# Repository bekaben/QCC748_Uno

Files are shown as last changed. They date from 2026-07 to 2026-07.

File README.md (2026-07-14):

# Arduino Uno Compatible Board Based on Qualcomm QCC748 SOM

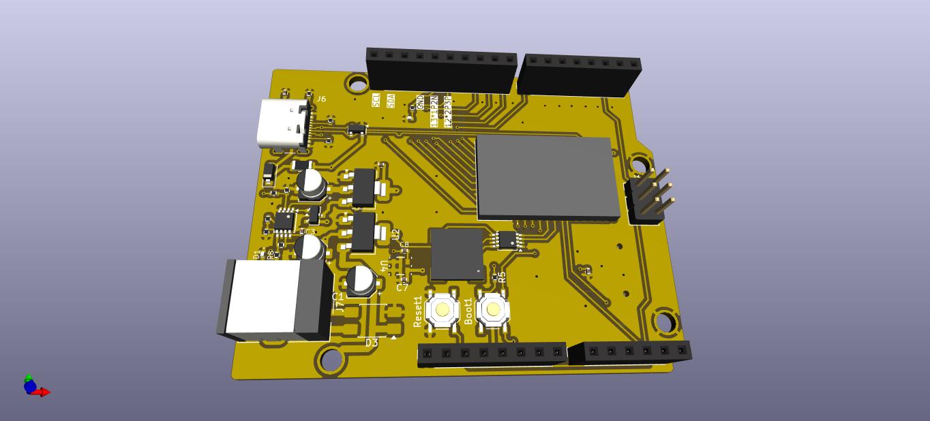
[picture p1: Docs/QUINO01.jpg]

<br>
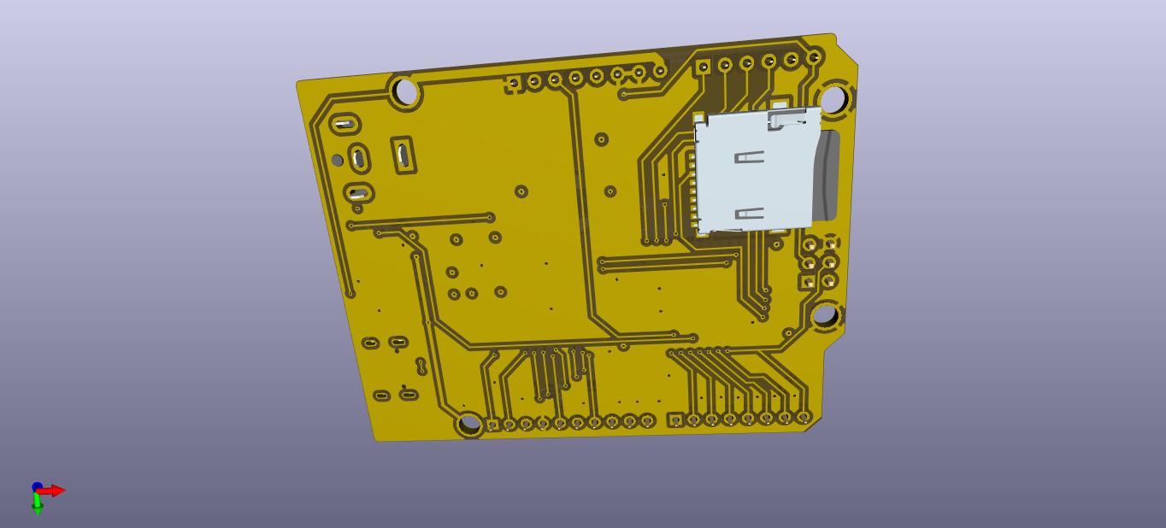
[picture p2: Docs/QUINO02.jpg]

<br>

This is a custom Arduino Uno-compatible board built around the Qualcomm QCC748 System-on-Module (SOM). This repository contains the full schematic, PCB layout, and supporting documentation for the board design.

## 🔧 Overview

This project implements an Arduino Uno form-factor development board using the Qualcomm QCC748 SOM as the core processing module. The design maintains compatibility with the Arduino Uno pinout while leveraging the QCC748's capabilities for enhanced wireless connectivity and processing performance. In addition, the board includes a speaker, microphone, and MicroSD card interface.

## Key Goals

\- ✅ Arduino Uno R3 mechanical footprint compatibility

\- ✅ Standard Arduino header pinout

\- ✅ USB programming interface

\- ✅ Power supply regulation (5V / 3.3V)

\- ✅ Wireless connectivity via QCC748 integrated Wifi and Bluetooth

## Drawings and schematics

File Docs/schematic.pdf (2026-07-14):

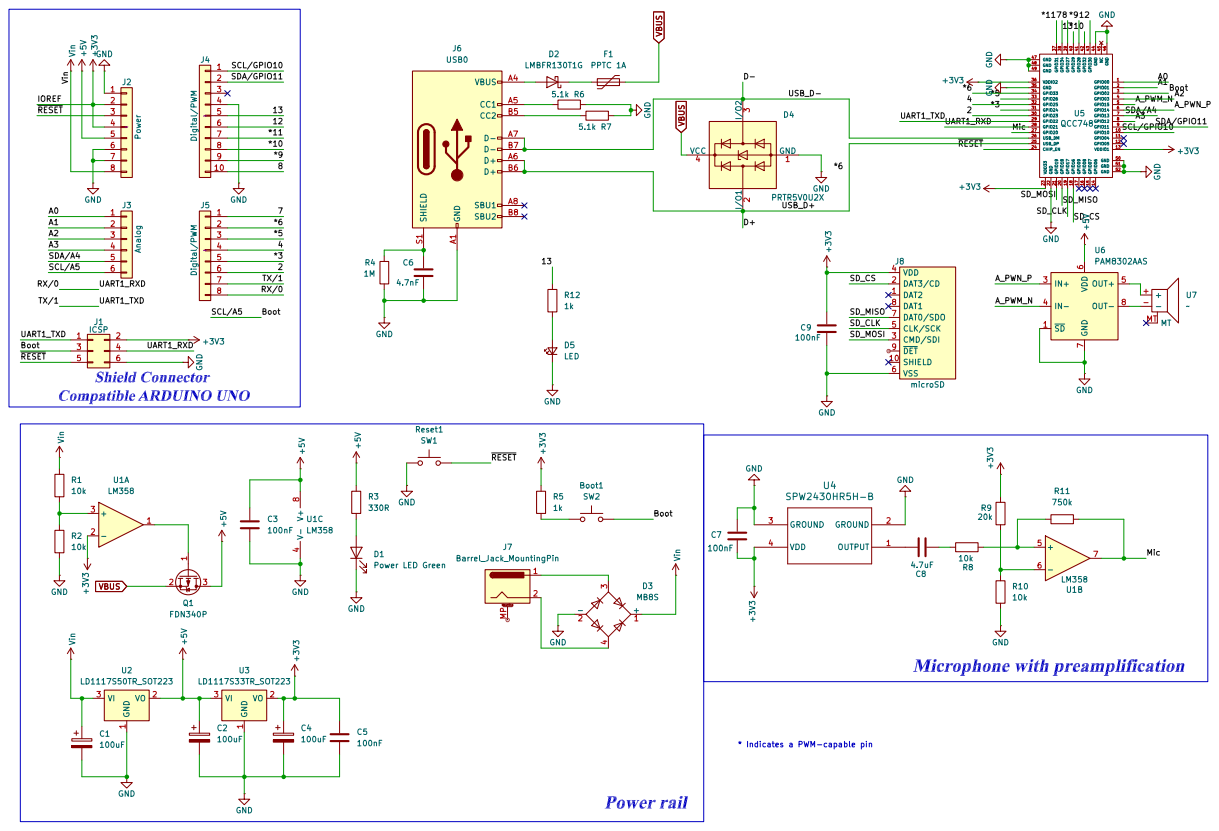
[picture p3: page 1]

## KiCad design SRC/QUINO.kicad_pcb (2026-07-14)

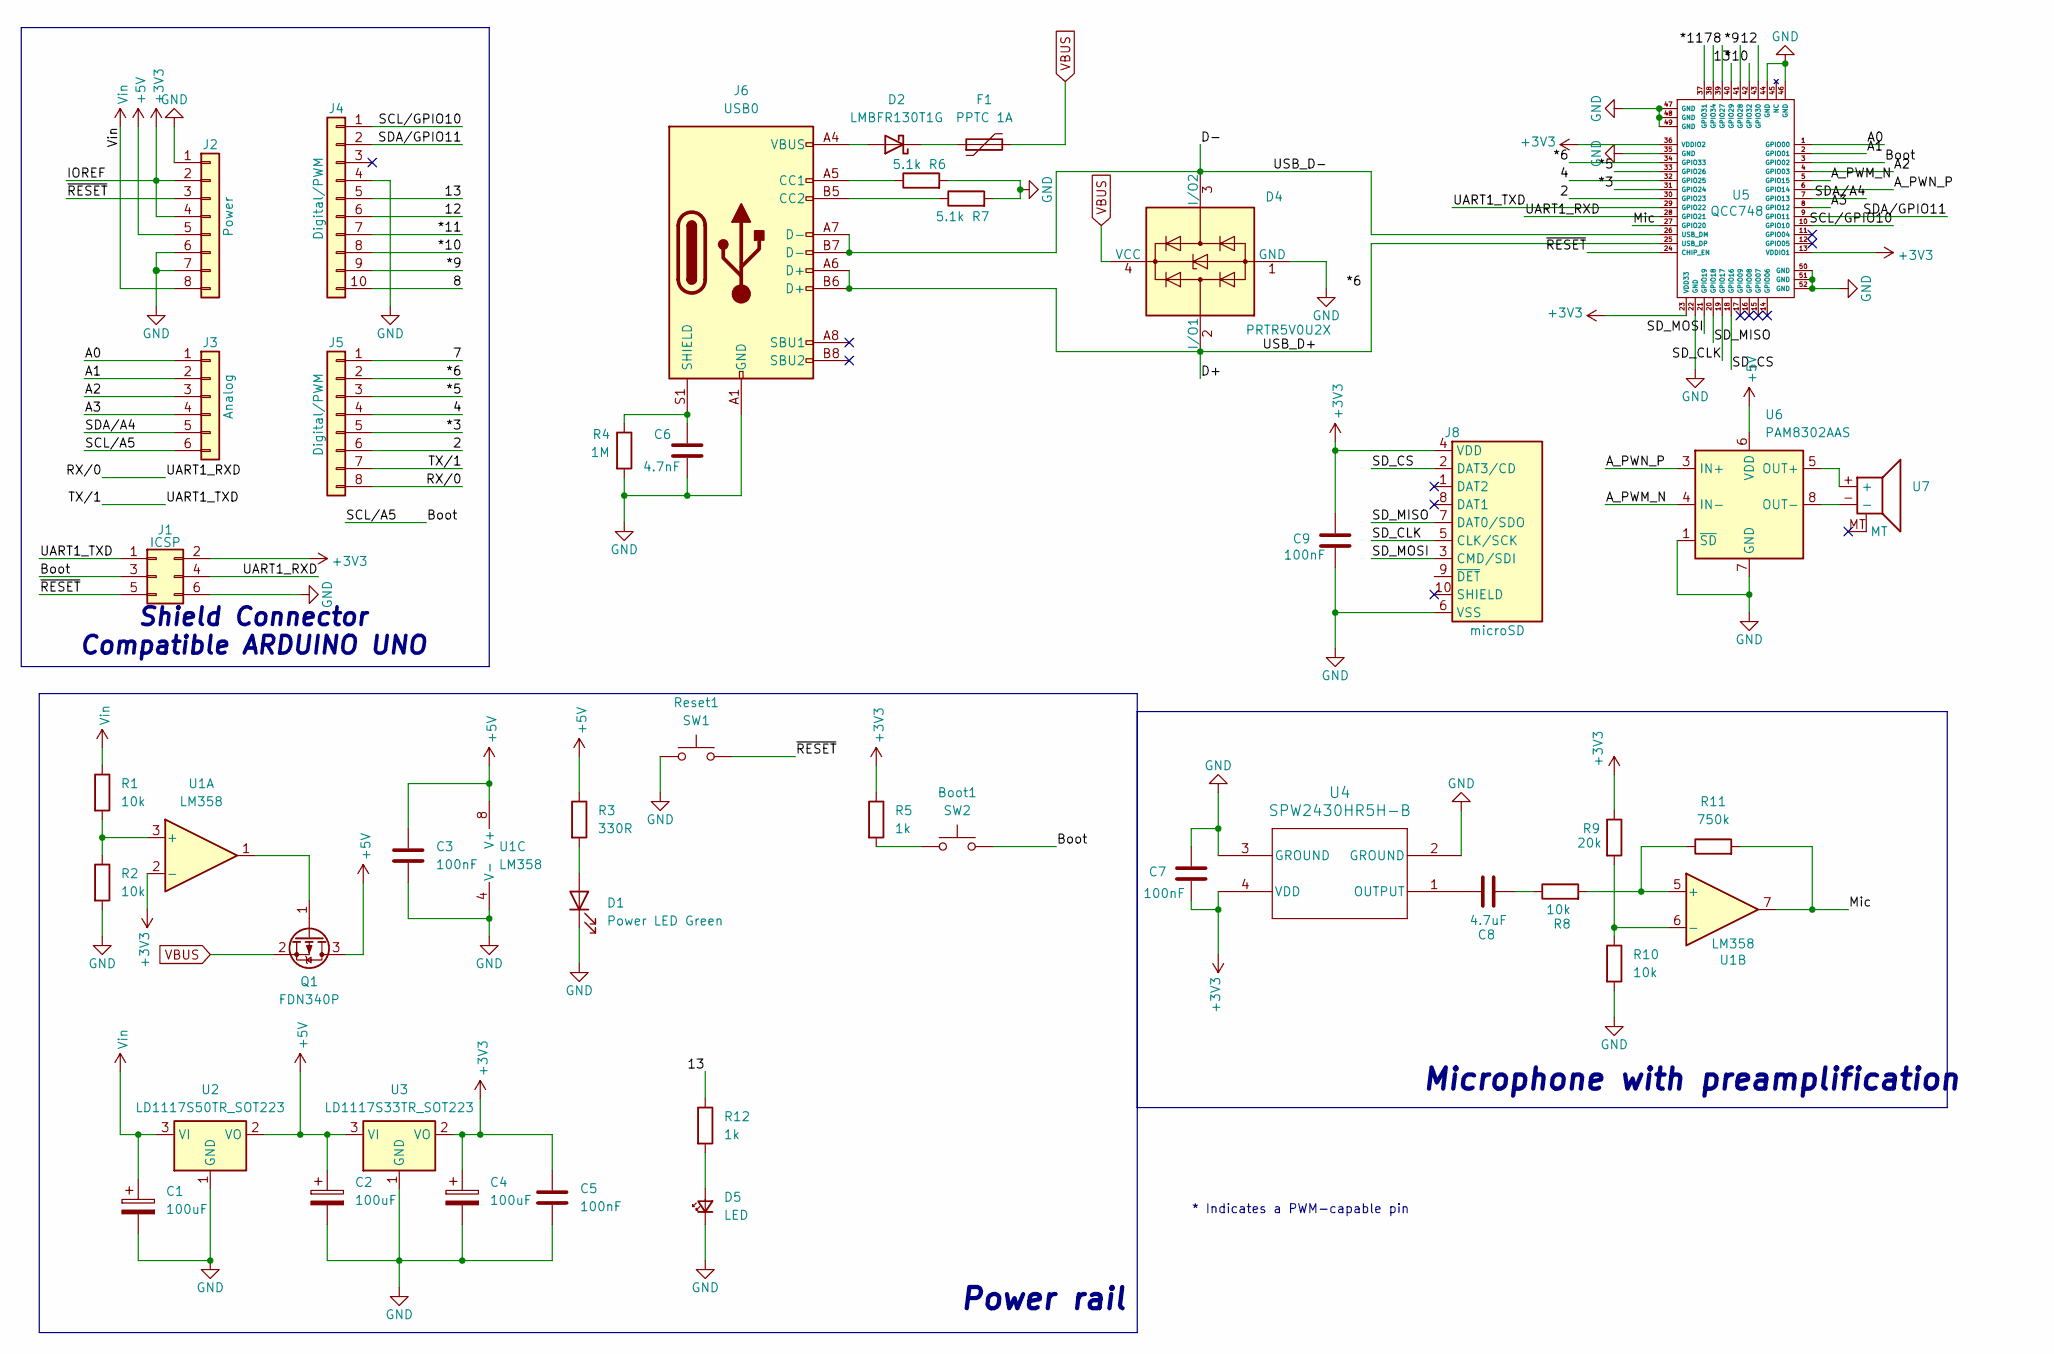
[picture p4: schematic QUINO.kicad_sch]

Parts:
Boot1: SW2; SW_Push_1P1T_XKB_TS-1187A
C1, C2, C4: 100uF; CP_Elec_4x3.9
C3, C5, C7, C9: 100nF; C_0402_1005Metric
C6: 4.7nF; C_0402_1005Metric
C8: 4.7uF; C_0402_1005Metric
D1: Power LED Green; LED_0402_1005Metric
D2: LMBFR130T1G; D_SOD-123
D4: PRTR5V0U2X; SOT-143
D5: LED; LED_0402_1005Metric
F1: PPTC 1A; Fuse_1206_3216Metric
J1: ICSP; PinHeader_2x03_P2.54mm_Vertical
J2: Power; PinSocket_1x08_P2.54mm_Vertical
J3: Analog; PinSocket_1x06_P2.54mm_Vertical
J4: Digital/PWM; PinSocket_1x10_P2.54mm_Vertical
J5: Digital/PWM; PinSocket_1x08_P2.54mm_Vertical
J6: USB0; USB_C_Receptacle_GCT_USB4105-xx-A_16P_TopMnt_Horizontal
J8: microSD; microSD_External_Pin
Q1: FDN340P; SOT-23
R1, R2, R8, R10: 10k; R_0402_1005Metric
R3: 330R; R_0402_1005Metric
R4: 1M; R_0402_1005Metric
R5, R12: 1k; R_0402_1005Metric
R6, R7: 5.1k; R_0402_1005Metric
R9: 20k; R_0402_1005Metric
R11: 750k; R_0402_1005Metric
Reset1: SW1; SW_Push_1P1T_XKB_TS-1187A
U1: LM358; TSSOP-8_3x3mm_P0.65mm
U2: LD1117S50TR_SOT223; SOT-223-3_TabPin2
U3: LD1117S33TR_SOT223; SOT-223-3_TabPin2
U4: SPW2430HR5H-B; SPW2430HR5H-B_KNO
U5: QCC748; QCC744M2LGM52MT010AA
U6: PAM8302AAS; MSOP-8_3x3mm_P0.65mm
U7: AD7504_SPK

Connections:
+3V3: C4.1, C5.1, C7.2, C9.1, J1.2, J2.2, J2.4, J8.4 (VDD), R5.1, R9.1, U1.2 (-), U3.2 (VO), U4.4 (VDD), U5.13 (VDDIO1), U5.23 (VDD33), U5.36 (VDDIO2)
+5V: C2.1, C3.1, J2.5, Q1.3 (D), R3.1, U1.8 (V+), U2.2 (VO), U3.3 (VI), U6.6 (VDD)
/2: J5.6, U5.30 (GPIO23)
/4: J5.4, U5.32 (GPIO25)
/7: J5.1, U5.38 (GPIO34)
/8: J4.10, U5.39 (GPIO27)
/12: J4.6, U5.43 (GPIO30)
/13: J4.5, R12.1, U5.40 (GPIO29)
/*3: J5.5, U5.31 (GPIO24)
/*5: J5.3, U5.33 (GPIO26)
/*6: J5.2, U5.34 (GPIO33)
/*9: J4.9, U5.41 (GPIO28)
/*10: J4.8, U5.42 (GPIO32)
/*11: J4.7, U5.37 (GPIO31)
/A0: J3.1, U5.1 (GPIO00)
/A1: J3.2, U5.2 (GPIO01)
/A2: J3.3, U5.4 (GPIO03)
/A3: J3.4, U5.8 (GPIO12)
/A_PWM_N: U5.5 (GPIO15), U6.4 (IN-)
/A_PWN_P: U5.6 (GPIO14), U6.3 (IN+)
/Boot: Boot1.2, J1.3, J3.6, U5.3 (GPIO02)
/D+: D4.2 (I/O1), J6.A6 (D+), J6.B6 (D+), U5.25 (USB_DP)
/D-: D4.3 (I/O2), J6.A7 (D-), J6.B7 (D-), U5.26 (USB_DM)
/Mic: R11.2, U1.7, U5.27 (GPIO20)
/RX/0: J1.4, J5.8, U5.28 (GPIO21)
/SCL/GPIO10: J4.1, U5.10 (GPIO10)
/SDA/A4: J3.5, U5.7 (GPIO13)
/SDA/GPIO11: J4.2, U5.9 (GPIO11)
/SD_CLK: J8.5 (CLK/SCK), U5.19 (GPIO17)
/SD_CS: J8.2 (DAT3/CD), U5.18 (GPIO16)
/SD_MISO: J8.7 (DAT0/SDO), U5.20 (GPIO18)
/SD_MOSI: J8.3 (CMD/SDI), U5.21 (GPIO19)
/TX/1: J1.1, J5.7, U5.29 (GPIO22)
/~RESET: J1.5, J2.3, Reset1.2, U5.24 (CHIP_EN)
GND: C1.2, C2.2, C3.2, C4.2, C5.2, C6.2, C7.1, C9.2, D1.1 (K), D4.1 (GND), D5.1 (K), J1.6, J2.1, J2.6, J2.7, J4.4, J6.A1 (GND), J6.A12 (GND), J6.B1 (GND), J6.B12 (GND), J8.6 (VSS), R2.2, R4.2, R6.2, R7.2, R10.2, Reset1.1, U1.4 (V-), U2.1 (GND), U3.1 (GND), U4.2 (GROUND), U4.3 (GROUND), U5.22 (GND), U5.35 (GND), U5.44 (GND), U5.46 (GND), U5.47 (GND), U5.48 (GND), U5.49 (GND), U5.50 (GND), U5.51 (GND), U5.52 (GND), U6.1 (~SD), U6.7 (GND); also elsewhere on the board
unnamed: Boot1.1, R5.2
unnamed: C8.2, R8.1
unnamed: D1.2 (A), R3.2
unnamed: D2.2 (A), J6.A4 (VBUS), J6.A9 (VBUS), J6.B4 (VBUS), J6.B9 (VBUS)
unnamed: D2.1 (K), F1.1
unnamed: D5.2 (A), R12.2
unnamed: J6.A5 (CC1), R6.1
unnamed: J6.B5 (CC2), R7.1
unnamed: C6.1, J6.S1 (SHIELD), R4.1
unnamed: Q1.1 (G), U1.1
unnamed: R1.2, R2.1, U1.3 (+)
unnamed: R8.2, R11.1, U1.5 (+)
unnamed: R9.2, R10.1, U1.6 (-)
unnamed: C8.1, U4.1 (OUTPUT)
unnamed: U6.5 (OUT+), U7.+
unnamed: U6.8 (OUT-), U7.-
VBUS: D4.4 (VCC), F1.2, Q1.2 (S); also elsewhere on the board
Vin: C1.1, J2.8, R1.1, U2.3 (VI); also elsewhere on the board

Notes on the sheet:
Shield Connector Compatible ARDUINO UNO
Microphone with preamplification
* Indicates a PWM-capable pin
Power rail

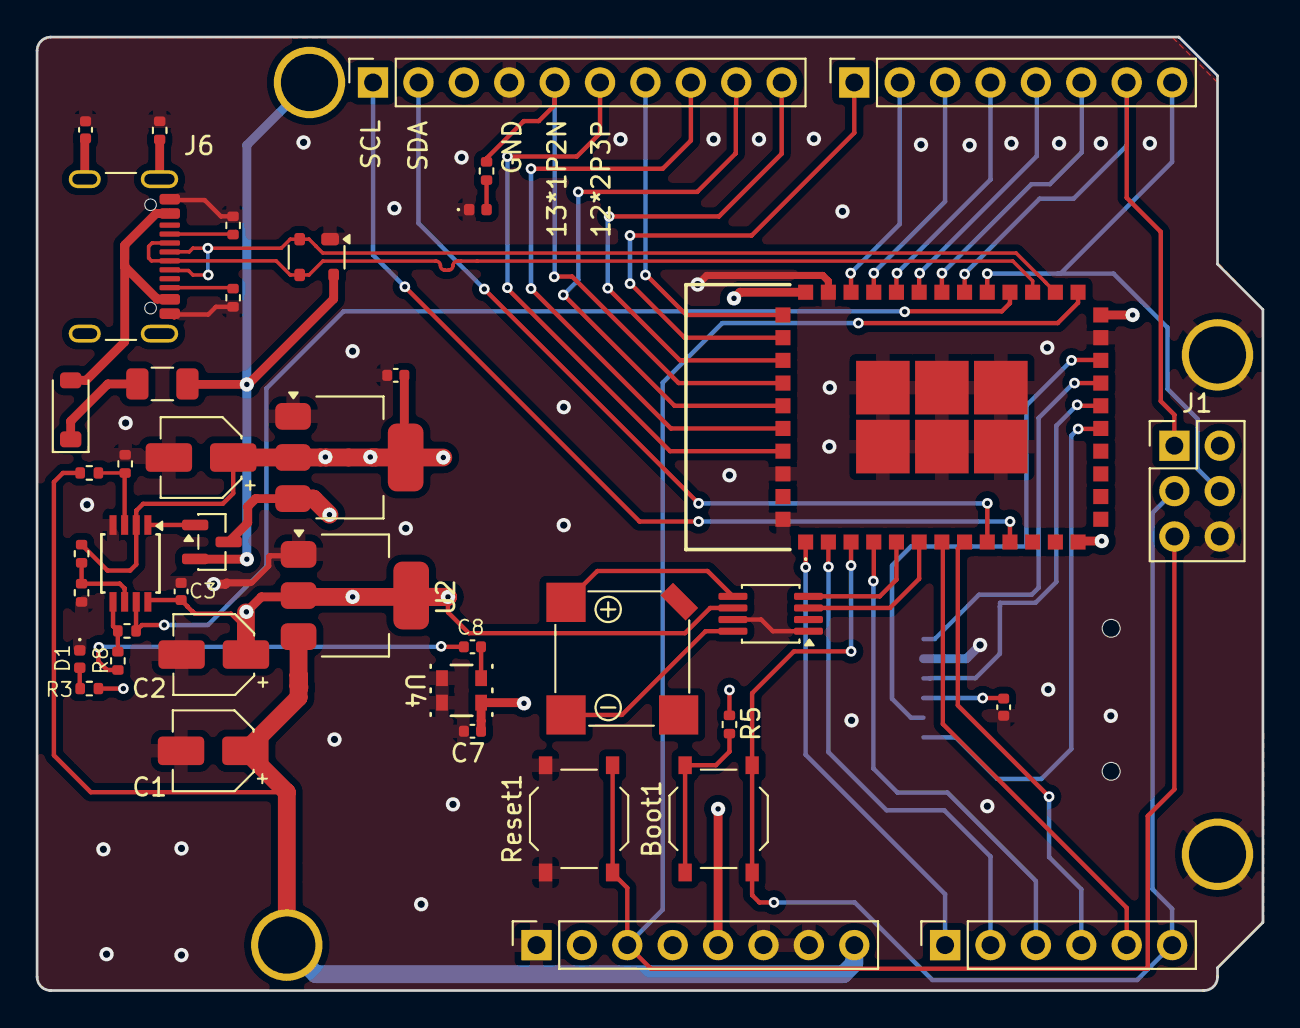
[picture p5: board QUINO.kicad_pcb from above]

Board: 4 copper layers, 68.6 x 53.3 mm, 47 parts (1 on the bottom side), 53 nets.

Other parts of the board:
MH1, MH2, MH3, MH4: MountingHole_3.2mm

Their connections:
GND: MH3.3, MH4.4; also elsewhere on the board
VBUS: MH1.2; also elsewhere on the board
Vin: MH2.1; also elsewhere on the board

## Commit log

2026-07-14 Add all repo files
    [QUINO.kicad_pcb, QUINO.kicad_sch]
2026-07-14 Update README with project schematic images
    Added project schematic images to the README.
